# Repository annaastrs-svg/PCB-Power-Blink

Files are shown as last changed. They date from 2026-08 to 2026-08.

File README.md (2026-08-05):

Power Blink  ;)
---
A power bank PCB Module designed in KiCAD, to safly charge lithium battery and u can look in the display the battery percentage on the oled screen
o m g 

Captura de pantalla 2026-08-05 142008
Captura de pantalla 2026-08-05 142235

Power blink charges though USB-C and delivers power though USB-A, with an onboard fuel gauge and microcontroller driving a small OLED display that shows the actuall battery charge level :B 

BTW BTW BTW low key look at my [JOURNAL.MD WOOWOWOWOWOWWOWOOOO!](https://github.com/annaastrs-svg/PCB-Power-Blink/blob/Pcb/Journal.md)

KiCAD
--
Esquematico
--
Captura de pantalla 2026-08-05 123812

PCB
--
Captura de pantalla 2026-08-05 142304

3D VIEW 
--
Captura de pantalla 2026-08-05 142138

PCB Huellas 
---
Captura de pantalla 2026-07-30 190930

CAD
---

 CAD detailes :
 
 The PCB is 55.8067 mm long & 40.9582 tall so i added 2 mm in all sides so it can fit in 

 the button is 6x6 mm
 
 the oled is 5.584 & 22.384 long
 
 the entry of c 14.4 long 
 
 the entry of a is 8.94 cm long 
 
 (btw ignore the pcb it was a scratch )
 

Captura de pantalla 2026-08-04 135139
Captura de pantalla 2026-08-04 135057

[look CAD file ](https://github.com/annaastrs-svg/PCB-Power-Blink/tree/Pcb/CAD)

BOM 
---
[BOM file ](https://github.com/annaastrs-svg/PCB-Power-Blink/blob/Pcb/Documentation/BOM.csv)

| Component | Purpose | Qty | Price | link|
|---|---|---|---|---|
| LiPo Battery 3.7V | Fuente de energía principal | 1 | ~$2.29 | i alrdy have one lolazo |
| TP4056-42-ESOP8 | IC de carga | 1 | ~$0.09 | [LCSC C16581](https://www.lcsc.com/product-detail/Battery-Management-ICs_TOPPOWER-Nanjing-Extension-Microelectronics-TP4056-42-ESOP8_C16581.html) |
| DW01A-G | Controlador de protección | 1 | ~$0.07 | [LCSC C61503](https://www.lcsc.com/product-detail/C61503.html) |
| FS8205A | MOSFETs de protección | 1 | ~$0.03 | [LCSC C908265](https://www.lcsc.com/product-detail/MOSFETs_FUXINSEMI-FS8205A_C908265.html) |
| MAX17048G+T10 | Fuel gauge (I2C) | 1 | ~$1.34 | [LCSC C2682616](https://www.lcsc.com/product-detail/C2682616.html) |
| ATtiny1614-SSN | Microcontrolador | 1 | ~$1.67 | [LCSC C614832](https://www.lcsc.com/product-detail/Microcontroller-Units-MCUs-MPUs-SOCs_Microchip-Tech-ATTINY1614-SSN_C614832.html) |
| MT3608 | Boost converter a 5V | 1 | ~$0.11 | [LCSC C84817](https://www.lcsc.com/product-detail/C84817.html) |
| USB-C Receptacle (Hroparts) | Entrada de carga | 1 | ~$0.10 | [LCSC C165948](https://www.lcsc.com/product-detail/C165948.html) |
| USB-A Receptacle THT | Salida de energía | 1 | ~$0.15 | genérico, cualquier tienda |
| OLED 0.91" I2C SSD1306 | Pantalla de batería | 1 | ~$1.20 | [AliExpress](https://www.aliexpress.com/item/33024849277.html) |
| Pulsador momentáneo 6mm | Despertar pantalla | 1 | ~$0.05 | genérico |
| SS34 Schottky | Diodo del boost | 1 | ~$0.05 | genérico |
| LEDs indicadores (CHRG/STDBY) | Indicadores de carga | 2 | ~$0.02 ea. | genérico |
| Resistencias SMD (varias) | 5.1k, 4.7k, 2.4k, 470, 1k, 10k, 75k | 10 | ~$0.01 ea. | genérico |
| Capacitores SMD (10-22µF) | Desacople/filtro | 6 | ~$0.03 ea. | genérico |

**Estimated Total: ~$8.00 USD (sin batería yey )**

## Connection table
[also look at the connection table](https://github.com/annaastrs-svg/PCB-Power-Blink/blob/Pcb/Documentation/Tabla%20de%20Conexiones.csv)

| Componente | Pin | → | Componente | Pin |
|---|---|---|---|---|
| J3 (USB-C) | VBUS | → | U8 (TP4056) | VCC |
| J3 (USB-C) | CC1, CC2 | → | GND | (vía R1, R2 5.1k) |
| U8 (TP4056) | CE | → | VCC | |
| U8 (TP4056) | CHRG | → | LED D2 | → VCC |
| U8 (TP4056) | STDBY | → | LED D1 | → VCC |
| U8 (TP4056) | PROG | → | GND | (vía 2.4k) |
| U8 (TP4056) | BAT | → | +BATT (raw) | |
| Batería | + | → | Q1 (FS8205A) | S1 |
| Batería | − | → | GND | |
| Q1 (FS8205A) | S2 | → | −BATT | |
| Q1 (FS8205A) | G1 | → | U3 (DW01A) | OD |
| Q1 (FS8205A) | D1/D2 | → | U3 (DW01A) | CS (vía R6 1k) |
| Q1 (FS8205A) | G2 | → | U3 (DW01A) | OC |
| U3 (DW01A) | VCC | → | +BATT | (vía R5 470) |
| U3 (DW01A) | GND | → | −BATT | |
| U4 (MAX17048) | VDD | → | +BATT | |
| U4 (MAX17048) | GND | → | GND | |
| U4 (MAX17048) | SDA, SCL | → | Bus I2C | (compartido con U5, U6) |
| U5 (ATtiny1614) | VDD | → | +BATT | |
| U5 (ATtiny1614) | GND | → | GND | |
| U5 (ATtiny1614) | PA1 | → | Bus I2C | SDA |
| U5 (ATtiny1614) | PA2 | → | Bus I2C | SCL |
| U5 (ATtiny1614) | PA3 | → | SW1 | (botón) |
| U5 (ATtiny1614) | PA0/UPDI | → | J2 | Header de programación |
| Bus I2C | SDA, SCL | → | GND | (vía R9, R10 4.7k a +BATT) |
| U6 (OLED) | VCC | → | +BATT | |
| U6 (OLED) | GND | → | GND | |
| U6 (OLED) | SDA, SCL | → | Bus I2C | |
| U1 (MT3608) | IN | → | +BATT | |
| U1 (MT3608) | GND | → | GND | |
| U1 (MT3608) | SW | → | L1, D3 | → VOUT |
| U1 (MT3608) | FB | → | R7 (10k)/R8 (75k) | divisor |
| U1 (MT3608) | EN | → | +BATT | |
| J1 (USB-A) | VBUS | → | VOUT | |
| J1 (USB-A) | D+, D− | → | (puenteados entre sí) | |
| J1 (USB-A) | GND | → | GND | |

TUTORIAL & HOW DOES ITR WORK? HUH 
--

Open the Power Blinck file, the schematic, and the PCB in KiCad.
The symbols and footprints of the components are not included by default in KiCAS, but I attached the footprints and symbols in the PCB files. 
Add them as a library before opening the project, run the ERC and DRC to make sure everything is clean. 
To manufacture, use the Gerber files; they can be uploaded directly to PCBWay and like that :B

The circuit is divided into 4 blocks. The input and charging part is the USB-C, which receives the charge, and the TP4056, which safely charges the battery. (TP4056 SAFE)

The battery and protection section, with the DW01A and FS8205A, protects the cell against overcharge, overdischarge, and short circuits. (DW01A , FS8205A PROTECTS )

The monitoring is done by the MAX17048, which measures the battery percentage, and the ARINY1614, which displays it on the OLED screen. (MAX17048 MEASURE , ARINY1614 READS AND SHOW  )

The power output is the MT3608, which boosts the battery voltage to a stable 5V for the USB-A port. (MT3608 STABLE VOLTAGES)

i loved making this pcb cus it looks easy but at the moment u see a lot of chips/modules with a lot of pins u cant avoid panic
in my projects i struggle a lot with power distribution and this had helpped me a lot :B 

PCB WAY 
--
THIS IS THE V.1 OF THE PROJECT !! (I did it 2 times cus i didnt like v.1)

Captura de pantalla 2026-07-30 205137

This is V.2 in PCB basics simulation of the pcb :B 



NOTES
---
This project was made for [MACONDO](https://macondo.hackclub.com/dashboard)

ill improve this project, there some things that ill change, maybe chips, modules or somthing like that. if u want to do this lil tutorial dont get mad at me if it doesnt work lolazo, Im 80 % sure it works !!

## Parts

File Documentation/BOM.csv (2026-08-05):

Component | Purpose | Qty | Price | Product
LiPo Battery 3.7V | Fuente de energia principal | 1 | ~$2.29 | (ya la tienes)
TP4056-42-ESOP8 | IC de carga | 1 | ~$0.09 | https://www.lcsc.com/product-detail/Battery-Management-ICs_TOPPOWER-Nanjing-Extension-Microelectronics-TP4056-42-ESOP8_C16581.html
DW01A-G | Controlador de proteccion | 1 | ~$0.07 | https://www.lcsc.com/product-detail/C61503.html
FS8205A | MOSFETs de proteccion | 1 | ~$0.03 | https://www.lcsc.com/product-detail/MOSFETs_FUXINSEMI-FS8205A_C908265.html
MAX17048G+T10 | Fuel gauge (I2C) | 1 | ~$1.34 | https://www.lcsc.com/product-detail/C2682616.html
ATtiny1614-SSN | Microcontrolador | 1 | ~$1.67 | https://www.lcsc.com/product-detail/Microcontroller-Units-MCUs-MPUs-SOCs_Microchip-Tech-ATTINY1614-SSN_C614832.html
MT3608 | Boost converter a 5V | 1 | ~$0.11 | https://www.lcsc.com/product-detail/C84817.html
USB-C Receptacle (Hroparts) | Entrada de carga | 1 | ~$0.10 | https://www.lcsc.com/product-detail/C165948.html
USB-A Receptacle THT | Salida de energia | 1 | ~$0.15 | generico - cualquier tienda
OLED 0.91in I2C SSD1306 | Pantalla de bateria | 1 | ~$1.20 | https://www.aliexpress.com/item/33024849277.html
Pulsador momentaneo 6mm | Despertar pantalla | 1 | ~$0.05 | generico
SS34 Schottky | Diodo del boost | 1 | ~$0.05 | generico
LEDs indicadores (CHRG/STDBY) | Indicadores de carga | 2 | ~$0.02 ea. | generico
Resistencias SMD varias | 5.1k, 4.7k, 2.4k, 470, 1k, 10k, 75k | 10 | ~$0.01 ea. | generico
Capacitores SMD (10-22uF) | Desacople/filtro | 6 | ~$0.03 ea. | generico

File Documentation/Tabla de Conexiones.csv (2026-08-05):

Componente Origen | Pin Origen | Componente Destino | Pin Destino | Notas
J3 (USB-C) | VBUS | U8 (TP4056) | VCC
J3 (USB-C) | CC1, CC2 | GND |  | via R1 y R2 (5.1k)
U8 (TP4056) | CE | VCC
U8 (TP4056) | CHRG | LED D2 |  | hacia VCC
U8 (TP4056) | STDBY | LED D1 |  | hacia VCC
U8 (TP4056) | PROG | GND |  | via resistencia 2.4k
U8 (TP4056) | BAT | +BATT (raw) |  | antes de proteccion
Bateria | + | Q1 (FS8205A) | S1
Bateria | - | GND
Q1 (FS8205A) | S2 | -BATT |  | nodo protegido
Q1 (FS8205A) | G1 | U3 (DW01A) | OD
Q1 (FS8205A) | D1/D2 | U3 (DW01A) | CS | via R6 (1k)
Q1 (FS8205A) | G2 | U3 (DW01A) | OC
U3 (DW01A) | VCC | +BATT |  | via R5 (470)
U3 (DW01A) | GND | -BATT
U4 (MAX17048) | VDD | +BATT
U4 (MAX17048) | GND | GND
U4 (MAX17048) | SDA | Bus I2C |  | compartido con U5 y U6
U4 (MAX17048) | SCL | Bus I2C |  | compartido con U5 y U6
U5 (ATtiny1614) | VDD | +BATT
U5 (ATtiny1614) | GND | GND
U5 (ATtiny1614) | PA1 | Bus I2C | SDA
U5 (ATtiny1614) | PA2 | Bus I2C | SCL
U5 (ATtiny1614) | PA3 | SW1 |  | boton
U5 (ATtiny1614) | PA0/UPDI | J2 |  | header de programacion
Bus I2C | SDA, SCL | +BATT |  | via R9 y R10 (4.7k pull-up)
U6 (OLED) | VCC | +BATT
U6 (OLED) | GND | GND
U6 (OLED) | SDA | Bus I2C
U6 (OLED) | SCL | Bus I2C
U1 (MT3608) | IN | +BATT
U1 (MT3608) | GND | GND
U1 (MT3608) | SW | L1, D3 | VOUT | inductor + diodo Schottky
U1 (MT3608) | FB | R7 (10k), R8 (75k) |  | divisor resistivo
U1 (MT3608) | EN | +BATT
J1 (USB-A) | VBUS | VOUT
J1 (USB-A) | D+ | D- |  | puenteados entre si
J1 (USB-A) | GND | GND

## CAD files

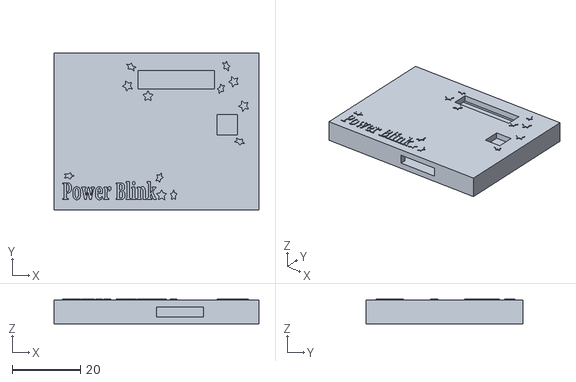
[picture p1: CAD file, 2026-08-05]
CAD/Power Blink ;B.stl
60.0 x 46.0 x 7.25

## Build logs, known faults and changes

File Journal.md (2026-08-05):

i did 2 version of this project lolazo  
so here is the jopurnal of v1 - v2

Just find a old module that charges my phone (i explote a battery with that module.. i think it wasnt functional)



esquematico 1 
Captura de pantalla 2026-07-30 130646

esquematico partes 
Captura de pantalla 2026-07-30 164605
Captura de pantalla 2026-07-30 164551
esquema completo 
Captura de pantalla 2026-07-30 190951

pcb 
Captura de pantalla 2026-07-30 185022
Captura de pantalla 2026-07-30 184352

pcb bien 

Captura de pantalla 2026-07-30 190232

3d view 
Captura de pantalla 2026-07-30 190120
Captura de pantalla 2026-07-30 190109

COSITASSSS V1
---
hola crayola
umm well the DRC always popped up with errors and told me nothing was connected, and no matter how many times I redid it, it wouldn’t fix, and it was always wrong, and it took me like 2 hours to do everything a thousand freaking times lol ki cad I hate you, jk ki cad I love you

the PCB hated how it looked and how modules C and A had to be stuck to the edge, and I wanted to keep it organized, but then I couldn’t connect things where they were supposed to go and I couldn’t do global labels, so I was stuck with the schematic and Gemini making the PCB...
I honestly thought, ah whatever, when I make it instead of the battery exploding, the module will explode lol

It was likeee 12 hours cus i did the pcb part like 3 times, also the eschematic sometimes was confusing like i didnt understand my self...

its like 8 dolars of chep components + 4 dolrs of pcb way to make it and like 10 for it to come to my house lolazo

V2
---
idk why im putting the same images u can see at the readme lollllllllllllllllllllllllllllll 

At this version i tryed to quit al errors and the eschematic and the pcb don have any error or at least i dont remember themm...

Captura de pantalla 2026-08-05 135639
Captura de pantalla 2026-08-05 132848

 just a bunch of advices 
 dumb thingssss.

 i tryed understanding the stuff of the gnd islands, moving a lot of vias(rieles) idk how to say it in english ermmm 
 anddd i thing all of this is clear yey 

esquematico 
Captura de pantalla 2026-08-05 133815

pcb 
Captura de pantalla 2026-08-05 140547

3d
Captura de pantalla 2026-08-05 142235

| Component | Purpose | Qty | Price | link|
|---|---|---|---|---|
| LiPo Battery 3.7V | Fuente de energía principal | 1 | ~$2.29 | i alrdy have one lolazo |
| TP4056-42-ESOP8 | IC de carga | 1 | ~$0.09 | [LCSC C16581](https://www.lcsc.com/product-detail/Battery-Management-ICs_TOPPOWER-Nanjing-Extension-Microelectronics-TP4056-42-ESOP8_C16581.html) |
| DW01A-G | Controlador de protección | 1 | ~$0.07 | [LCSC C61503](https://www.lcsc.com/product-detail/C61503.html) |
| FS8205A | MOSFETs de protección | 1 | ~$0.03 | [LCSC C908265](https://www.lcsc.com/product-detail/MOSFETs_FUXINSEMI-FS8205A_C908265.html) |
| MAX17048G+T10 | Fuel gauge (I2C) | 1 | ~$1.34 | [LCSC C2682616](https://www.lcsc.com/product-detail/C2682616.html) |
| ATtiny1614-SSN | Microcontrolador | 1 | ~$1.67 | [LCSC C614832](https://www.lcsc.com/product-detail/Microcontroller-Units-MCUs-MPUs-SOCs_Microchip-Tech-ATTINY1614-SSN_C614832.html) |
| MT3608 | Boost converter a 5V | 1 | ~$0.11 | [LCSC C84817](https://www.lcsc.com/product-detail/C84817.html) |
| USB-C Receptacle (Hroparts) | Entrada de carga | 1 | ~$0.10 | [LCSC C165948](https://www.lcsc.com/product-detail/C165948.html) |
| USB-A Receptacle THT | Salida de energía | 1 | ~$0.15 | genérico, cualquier tienda |
| OLED 0.91" I2C SSD1306 | Pantalla de batería | 1 | ~$1.20 | [AliExpress](https://www.aliexpress.com/item/33024849277.html) |
| Pulsador momentáneo 6mm | Despertar pantalla | 1 | ~$0.05 | genérico |
| SS34 Schottky | Diodo del boost | 1 | ~$0.05 | genérico |
| LEDs indicadores (CHRG/STDBY) | Indicadores de carga | 2 | ~$0.02 ea. | genérico |
| Resistencias SMD (varias) | 5.1k, 4.7k, 2.4k, 470, 1k, 10k, 75k | 10 | ~$0.01 ea. | genérico |
| Capacitores SMD (10-22µF) | Desacople/filtro | 6 | ~$0.03 ea. | genérico |

cad 
Captura de pantalla 2026-08-04 135509
Captura de pantalla 2026-08-04 135130

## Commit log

2026-07-31 KiCad file
2026-07-31 archivos Gerber
2026-08-04 Huuuuge PCB file
    [powerblink-B_Cu.gbr, powerblink-B_Mask.gbr, powerblink-B_Paste.gbr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]
2026-08-05 KiCAD PCB Files
    [powerblink-B_Cu.gbr, powerblink-B_Mask.gbr, powerblink-B_Paste.gbr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]
2026-08-05 Documentation Files
    [BOM.csv, Tabla de Conexiones.csv]
2026-08-05 Revise README with project details and tutorial
    Updated README.md to enhance project description and details, including specifications, components, and tutorial for the Power Blink PCB module.
